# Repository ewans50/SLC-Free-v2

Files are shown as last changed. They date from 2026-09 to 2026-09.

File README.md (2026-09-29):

I'm not a creator of this product, please see https://www.14point7.com/pages/software-and-documentation for latest updates from the creator

SLC Free 2 is licensed under GNU GPL V3

Use Cypress PSOC Designer 5.4 to build/compile Firmware

Prebuilt hex files that are ready to program onto blank uCs using the PSOC Programmer Software and PSOC MiniProg hardware are contained in the "Firmware\Prebuilt_Hex" directory

PCB_Gerber_6mil_Trace_Spacing.rar in "PCB" directory are the Gerber files that you can submit to PCB fabrication places

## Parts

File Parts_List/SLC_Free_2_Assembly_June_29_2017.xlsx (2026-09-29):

Item # | Qty | PCB Ref | Value | Digikey Part No. | Package | Type | Top/Bottom
1 | 1 | C1 | 4.7uf | 399-7049-1-ND | 1210 | SMT | Top
2 | 4 | C2, C4, C5, C11 | 100nf | 1276-6557-1-ND | 805 | SMT | Top
3 | 1 | C3 | 10uf | 587-3485-1-ND | 1206 | SMT | Top
4 | 4 | C6, C7 C9, C10 | 1uf | 1276-6606-1-ND | 805 | SMT | Top
5 | 1 | C8 | 10nf | 1276-6845-1-ND | 805 | SMT | Top
6 | 1 | D1 | Diode Schottky | B190BQ-13-FDICT-ND | SMB | SMT | Top
7 | 1 | D2 | Diode TVS | F6314CT-ND | SMB | SMT | Top
8 | 1 | D3 | Diode Schottky | NRVTS245ESFT1GOSCT-ND | SOD123F | SMT | Top
9 | 1 | IC1 | NFET | 1727-5508-1-ND | TO-252 | SMT | Top
10 | 1 | IC2 | 5V Reg | NCV78M05BDTRKGOSCT-ND | TO-252-3 | SMT | Top
11 | 1 | IC3 | CY8C24423A-24PVXI | Will supply part | 28-SSOP | SMT | Top
12 | 1 | JP1 | DNP | DNP | DNP | TH | Top
13 | 1 | JP2 | DNP | DNP | DNP | TH | Top
14 | 1 | JP3 | DNP | DNP | DNP | TH | Top
15 | 1 | JP4 | DNP | DNP | DNP | TH | Top
16 | 1 | JP5 | DNP | DNP | DNP | TH | Top
17 | 1 | R1 | 10 | RMCF1206JT10R0CT-ND | 1206 | SMT | Top
18 | 1 | R14 | 4.7k | RMCF0805FT4K70CT-ND | 805 | SMT | Top
19 | 1 | R15 | 1.2k | RMCF0805FT1K20CT-ND | 805 | SMT | Top
20 | 1 | R16 | 100 | RMCF1206JT100RCT-ND | 1206 | SMT | Top
21 | 6 | R2, R6, R8, R11, R12, R13 | 1k | RMCF0805FT1K00CT-ND | 805 | SMT | Top
22 | 2 | R5,R9 | 1k 0.1% | P1.0KDACT-ND | 805 | SMT | Top
23 | 1 | R3 | 61.9 0.1% | P61.9DACT-ND | 805 | SMT | Top
24 | 1 | R10 | 10k | RMCF0805FT10K0CT-ND | 805 | SMT | Top
25 | 1 | R4 | 10k 0.1% | P10KDACT-ND | 805 | SMT | Top
26 | 1 | R7 | 120k | RMCF0805FT120KCT-ND | 805 | SMT | Top
27 | 1 | S1 | DNP | DNP | DNP | TH | Top

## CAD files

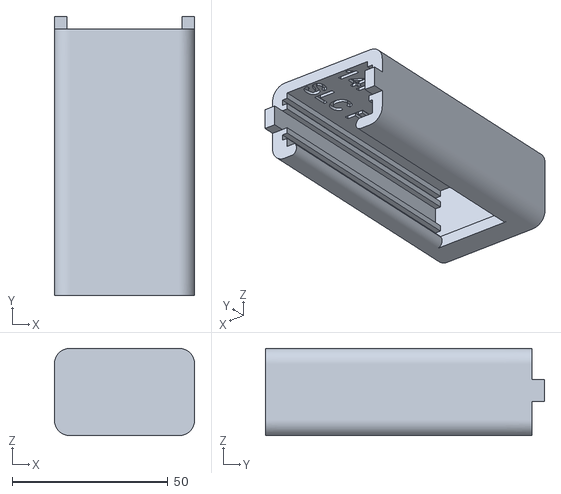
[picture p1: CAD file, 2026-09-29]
3d/STL/SF2_Case.stl
45.0 x 89.5 x 28.0

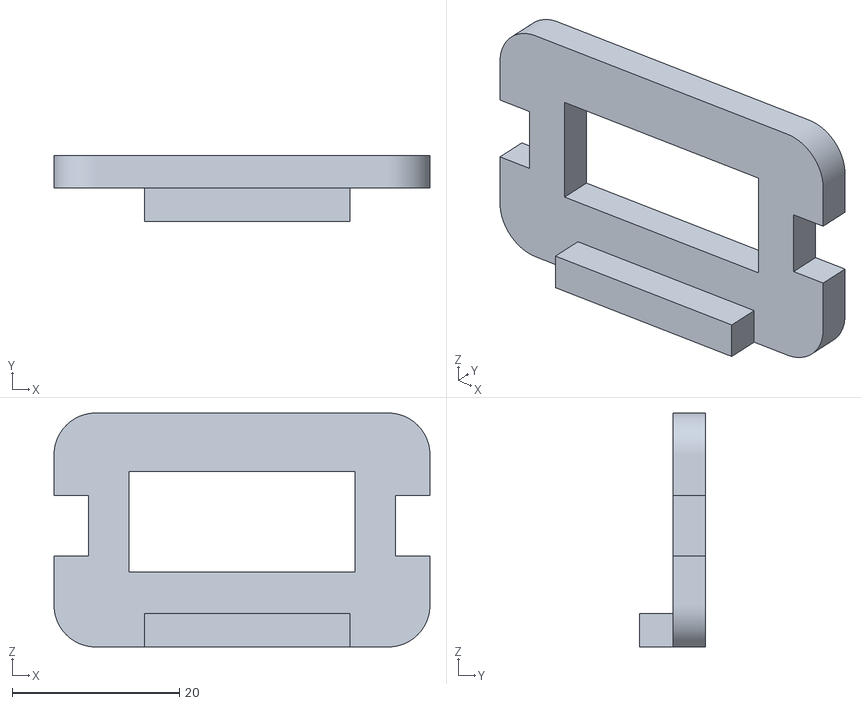
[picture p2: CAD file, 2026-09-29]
3d/STL/SF2_Cap.stl
45.0 x 7.90 x 28.0

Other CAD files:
3d/Fusion360/SF2_Cap_Jan_7_2019 v5.f3d
3d/Fusion360/SF2_Case_Jan_7_2019 v5.f3d

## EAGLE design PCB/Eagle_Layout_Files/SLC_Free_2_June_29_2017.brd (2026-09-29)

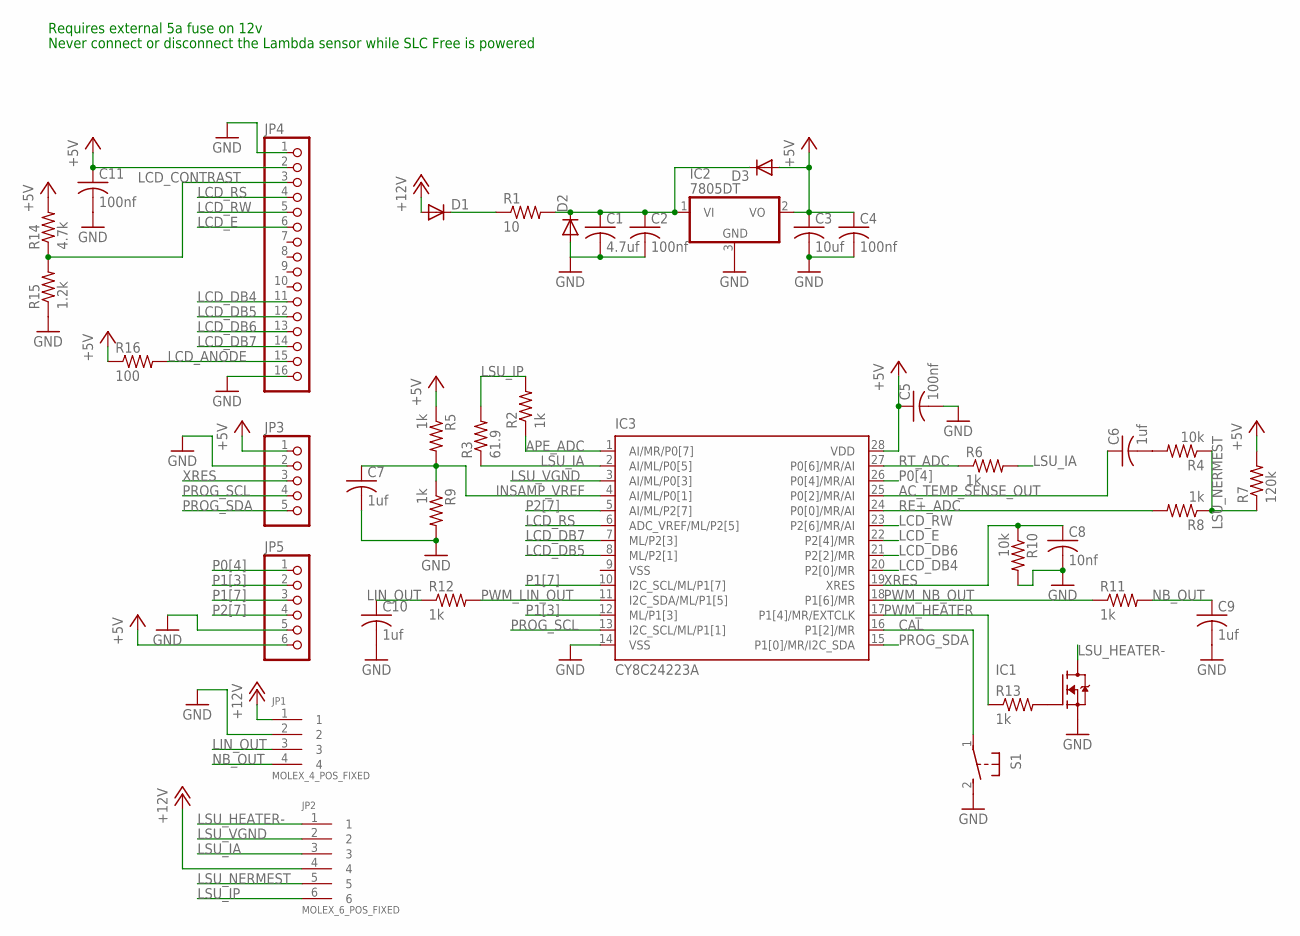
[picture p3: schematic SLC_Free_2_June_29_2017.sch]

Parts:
C1: 4.7uf; C1210
C2, C4, C5, C11: 100nf; C0805
C3: 10uf; C1206
C6, C7, C9, C10: 1uf; C0805
C8: 10nf; C0805
D1, D2: DIODE-SMB; SMB
D3: DIODE-SOD123; SOD123
IC1: FET_NMOS_T0252; T0252
IC2: 7805DT; TO252
IC3: CY8C24223A; SSOP28
JP1: MOLEX_4_POS_FIXED
JP2: MOLEX_6_POS_FIXED
JP3: PINHD-1X5; 1X05
JP4: PINHD-1X16; 1X16
JP5: PINHD-1X6; 1X06
R1: 10; R1206
R2, R5, R6, R8, R9, R11, R12, R13: 1k; R0805
R3: 61.9; R0805
R4, R10: 10k; R0805
R7: 120k; R0805
R14: 4.7k; R0805
R15: 1.2k; R0805
R16: 100; R1206
S1: 31-XX; B3F-31XX

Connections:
+5V: C3.1, C4.1, C5.1, C11.1, D3.A, IC2.2 (VO), IC3.28 (VDD), JP3.1, JP4.2, JP5.6, R5.1, R7.2, R14.2, R16.1
+12V: D1.A, JP1.1, JP2.4
AC_TEMP_SENSE_OUT: C6.1, IC3.25 (P0[2]/MR/AI)
APE_ADC: IC3.1 (AI/MR/P0[7]), R2.1
CAL: IC3.16 (P1[2]/MR), S1.1
GND: C1.2, C2.2, C3.2, C4.2, C5.2, C7.2, C8.2, C9.2, C10.2, C11.2, D2.A, IC1.2 (S), IC2.3 (GND), IC3.14 (VSS), JP1.2, JP3.2, JP4.1, JP4.16, JP5.5, R9.2, R10.2, R15.1, S1.2 (S)
INSAMP_VREF: C7.1, IC3.4 (AI/ML/P0[1]), R5.2, R9.1
LCD_ANODE: JP4.15, R16.2
LCD_CONTRAST: JP4.3, R14.1, R15.2
LCD_DB4: IC3.20 (P2[0]/MR), JP4.11
LCD_DB5: IC3.8 (ML/P2[1]), JP4.12
LCD_DB6: IC3.21 (P2[2]/MR), JP4.13
LCD_DB7: IC3.7 (ML/P2[3]), JP4.14
LCD_E: IC3.22 (P2[4]/MR), JP4.6
LCD_RS: IC3.6 (ADC_VREF/ML/P2[5]), JP4.4
LCD_RW: IC3.23 (P2[6]/MR/AI), JP4.5
LIN_OUT: C10.1, JP1.3, R12.1
LSU_HEATER-: IC1.3 (D), JP2.1
LSU_IA: IC3.2 (AI/ML/P0[5]), JP2.3, R3.1, R6.2
LSU_IP: JP2.6, R2.2, R3.2
LSU_NERMEST: JP2.5, R4.1, R7.1, R8.1
LSU_VGND: IC3.3 (AI/ML/P0[3]), JP2.2
unnamed: C6.2, R4.2
unnamed: C1.1, C2.1, D2.C, D3.C, IC2.1 (VI), R1.2
unnamed: IC1.1 (G), R13.2
unnamed: D1.C, R1.1
NB_OUT: C9.1, JP1.4, R11.2
P0[4]: IC3.26 (P0[4]/MR/AI), JP5.1
P1[3]: IC3.12 (ML/P1[3]), JP5.2
P1[7]: IC3.10 (I2C_SCL/ML/P1[7]), JP5.3
P2[7]: IC3.5 (AI/ML/P2[7]), JP5.4
PROG_SCL: IC3.13 (I2C_SCL/ML/P1[1]), JP3.4
PROG_SDA: IC3.15 (P1[0]/MR/I2C_SDA), JP3.5
PWM_HEATER: IC3.17 (P1[4]/MR/EXTCLK), R13.1
PWM_LIN_OUT: IC3.11 (I2C_SDA/ML/P1[5]), R12.2
PWM_NB_OUT: IC3.18 (P1[6]/MR), R11.1
RE+_ADC: IC3.24 (P0[0]/MR/AI), R8.2
RT_ADC: IC3.27 (P0[6]/MR/AI), R6.1
VSS: IC3.9 (VSS)
XRES: C8.1, IC3.19 (XRES), JP3.3, R10.1

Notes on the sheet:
Requires external 5a fuse on 12v
Never connect or disconnect the Lambda sensor while SLC Free is powered

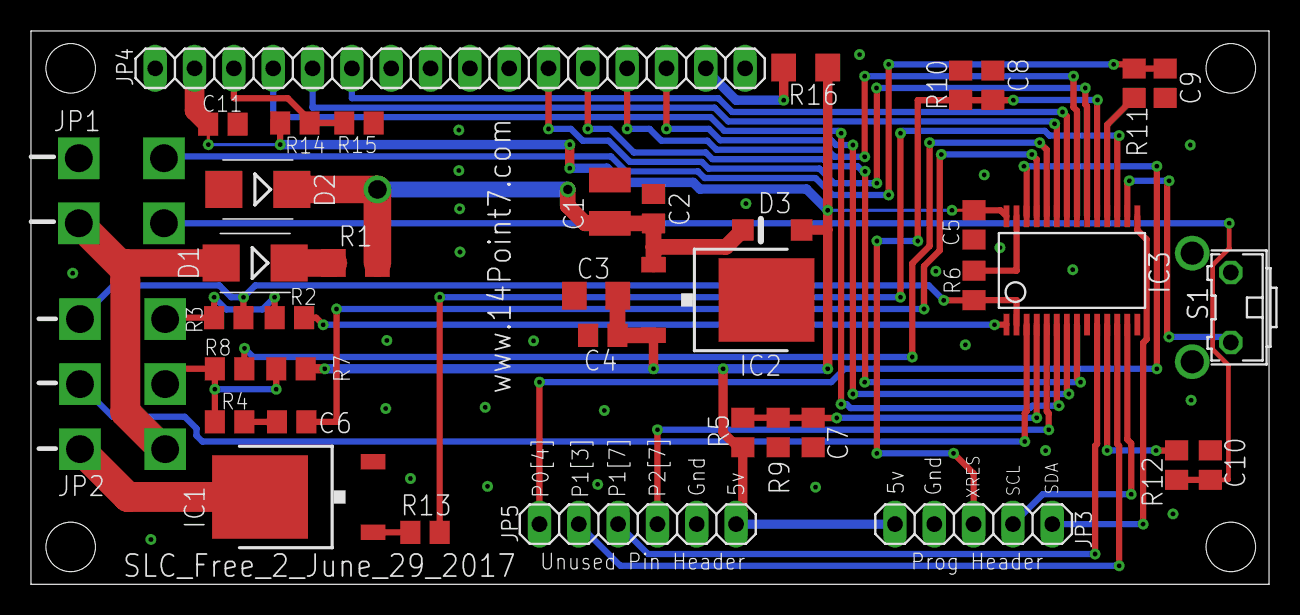
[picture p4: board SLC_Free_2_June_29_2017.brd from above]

Board: 2 copper layers, 80.0 x 35.7 mm, 39 parts (0 on the bottom side), 39 nets.

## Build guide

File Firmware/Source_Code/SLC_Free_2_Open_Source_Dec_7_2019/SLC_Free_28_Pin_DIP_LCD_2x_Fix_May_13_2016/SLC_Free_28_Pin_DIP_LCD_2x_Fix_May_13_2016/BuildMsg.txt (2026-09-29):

Starting MAKE...
creating project.mk 

lib/adcinc.asm

lib/adcincint.asm

lib/amux4_0.asm

lib/amux4_1.asm

lib/dac6_vgnd.asm

lib/dac9_ia.asm

lib/insamp.asm

lib/lcd.asm

lib/psocconfig.asm

lib/psocconfigtbl.asm

lib/pwm8_heater.asm

lib/pwm8_heaterint.asm

lib/pwm8_nb_out.asm

lib/pwm8_nb_outint.asm

lib/pwm8_vout.asm

lib/pwm8_voutint.asm

lib/sleeptimer.asm

lib/sleeptimerint.asm

./boot.asm

Linking..

symbol ADCINC_bGetData is unused

symbol SleepTimer_bGetTickCntr is unused

symbol PWM8_Heater_bReadCounter is unused

symbol ADCINC_iGetData is unused

symbol SleepTimer_iGetTickCntr is unused

symbol SleepTimer_lGetTickCntr is unused

symbol PWM8_Vout_EnableInt is unused

symbol PWM8_Vout_Stop is unused

symbol SleepTimer_TickWait is unused

symbol PWM8_Vout_bReadPulseWidth is unused

symbol PWM8_NB_Out_EnableInt is unused

symbol SleepTimer_SetTimer is unused

symbol SleepTimer_SyncWait is unused

symbol ADCINC_Stop is unused

symbol PWM8_Heater_EnableInt is unused

symbol PWM8_NB_Out_Stop is unused

symbol ADCINC_fClearFlag is unused

symbol INSAMP_Stop is unused

symbol SleepTimer_bGetTimer is unused

symbol PWM8_Heater_Stop is unused

symbol PWM8_NB_Out_bReadPulseWidth is unused

symbol SleepTimer_Stop is unused

symbol AMUX4_0_Stop is unused

symbol AMUX4_1_Stop is unused

symbol PWM8_Vout_WritePeriod is unused

symbol DAC9_Ia_Stop is unused

symbol ADCINC_WritePulseWidth is unused

symbol ADCINC_fIsDataAvailable is unused

symbol PWM8_Heater_bReadPulseWidth is unused

symbol SleepTimer_DisableInt is unused

symbol LCD_PrHexInt is unused

symbol PWM8_Vout_bReadCounter is unused

symbol DAC9_Ia_WriteBlind is unused

symbol ADCINC_cClearFlagGetData is unused

symbol AMUX4_0_Start is unused

symbol AMUX4_1_Start is unused

symbol ADCINC_StopADC is unused

symbol PWM8_NB_Out_WritePeriod is unused

symbol DAC6_VGND_Stop is unused

symbol PWM8_Heater_WritePeriod is unused

symbol PWM8_NB_Out_bReadCounter is unused

symbol INSAMP_SetGain is unused

symbol DAC6_VGND_WriteBlind is unused

427 bytes unused code deleted

3561 bytes before Code Compression, 2892 after. 6% reduction.

  ROM 91% full. 3695 out of 4096 bytes used (does not include absolute areas).

  RAM 43% full. 110 bytes used (does not include stack usage).

Built with ICCM8C STD V7.05.00

SLC_Free_28_Pin_DIP_LCD_2x_Fix_May_13_2016 - 0 error(s) 0 warning(s) 22:01:23

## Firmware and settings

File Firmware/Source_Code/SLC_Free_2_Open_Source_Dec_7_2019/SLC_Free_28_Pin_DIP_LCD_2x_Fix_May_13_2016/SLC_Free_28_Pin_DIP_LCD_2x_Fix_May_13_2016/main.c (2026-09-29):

//----------------------------------------------------------------------------
// C main line
//----------------------------------------------------------------------------

#include <m8c.h>        // part specific constants and macros
#include "PSoCAPI.h"    // PSoC API definitions for all User Modules
extern BYTE ADC_Counter; //Variable Declared in ADCININT.asm
extern BYTE Ri_Max_x1; //Variable Declared in ADCININT.asm
extern BYTE Ri_Min_x1; //Variable Declared in ADCININT.asm
extern BYTE ip_x1; //Variable Declared in ADCININT.asm
extern BYTE ADC_IF; //Variable Declared in ADCININT.asm
extern BYTE Sleep_Counter; //Variable Declared in SleepTimerINT.asm

#define Vout_Lookup_Counter_Set 25
#define LCD_Counter_Set 50

#define Lin_Out
#define NB_Out
#define LCD_Lambda_Text
//#define LCD_AFR_Text
//#define LCD_Lambda_Graph
#define LCD_Temperature_Text
//#define LCD_Temperature_Graph
//#define PID_Tune
#define Ri_Filter_Strength 4
#define ip_Filter_Strength 4

#ifdef PID_Tune
	INT Ri_Mid_Target= 286;//271; //
	INT Ia_PID_Kp = 25;
	INT Ia_PID_Ki = 4;
	INT Ia_Output_Bias = 256;
	INT Ri_Delta_Target=143; //PID Target peak to peak Voltage of Nermest Cell
	INT Heater_PID_Kp =-72;
	INT Heater_PID_Ki =-4;
	INT Heater_PID_Output_Bias =128;
#else
	#define Ri_Mid_Target 286 //271 //256+14.769 = 2.53v = 2.08v(VGND) + 0.45v, PID Target Voltage of Nermest Cell
	#define Ia_PID_Kp 25
	#define Ia_PID_Ki 4
	#define Ia_Output_Bias 256
	#define Ri_Delta_Target 143 //PID Target peak to peak Voltage of Nermest Cell
	#define Heater_PID_Kp -72
	#define Heater_PID_Ki -4
	#define Heater_PID_Output_Bias 128
#endif

#ifdef Lin_Out
	#define ip_to_Vout_Lookup_Start 135
	#define ip_to_Vout_Lookup_Size 158
	const BYTE ip_to_Vout_Lookup[ip_to_Vout_Lookup_Size] = {0,1,1,2,3,4,4,5,6,7,8,8,9,10,11,12,12,13,14,15,16,17,17,18,19,20,21,22,22,23,24,25,26,27,27,28,29,30,31,32,33,34,34,35,36,37,38,39,40,41,42,43,44,44,45,46,47,48,49,50,51,52,53,54,55,56,57,58,59,60,61,62,63,64,65,66,67,68,69,70,71,72,73,74,76,77,78,79,80,81,82,83,84,86,87,88,89,90,91,92,94,95,96,97,98,100,101,102,103,105,106,107,108,110,111,112,113,115,116,117,119,120,123,126,129,132,135,138,141,144,147,151,154,157,161,164,168,171,175,178,182,186,190,194,197,201,206,210,214,218,222,227,231,236,240,245,250,255}; 
#endif
	
#ifdef LCD_AFR_Text
	#define ip_to_Lambda_Lookup_Start 135
	#define ip_to_Lambda_Lookup_Size 158
	const BYTE ip_to_Lambda_Lookup[ip_to_Lambda_Lookup_Size]={100,100,100,101,101,101,102,102,102,103,103,103,104,104,104,105,105,105,105,106,106,106,107,107,107,108,108,108,109,109,109,110,110,110,111,111,111,112,112,112,113,113,113,114,114,115,115,115,116,116,116,117,117,117,118,118,118,119,119,120,120,120,121,121,122,122,122,123,123,123,124,124,125,125,125,126,126,127,127,127,128,128,129,129,130,130,130,131,131,132,132,133,133,133,134,134,135,135,136,136,137,137,138,138,139,139,139,140,140,141,141,142,142,143,143,144,144,145,145,146,146,147,148,149,150,152,153,154,155,156,158,159,160,162,163,164,166,167,168,170,171,173,174,176,177,179,181,182,184,185,187,189,191,192,194,196,198,200};//4.9
#endif

#ifdef LCD_Lambda_Text
	#define ip_to_Lambda_Lookup_Start 135
	#define ip_to_Lambda_Lookup_Size 158
	const BYTE ip_to_Lambda_Lookup[ip_to_Lambda_Lookup_Size]={68,68,68,69,69,69,69,69,70,70,70,70,70,71,71,71,71,72,72,72,72,72,73,73,73,73,74,74,74,74,74,75,75,75,75,76,76,76,76,76,77,77,77,77,78,78,78,78,79,79,79,79,80,80,80,80,81,81,81,81,82,82,82,82,83,83,83,83,84,84,84,85,85,85,85,86,86,86,86,87,87,87,88,88,88,88,89,89,89,90,90,90,91,91,91,91,92,92,92,93,93,93,94,94,94,95,95,95,96,96,96,97,97,97,98,98,98,99,99,99,100,100,101,102,102,103,104,105,106,106,107,108,109,110,111,112,113,114,115,116,117,118,119,120,121,122,123,124,125,126,127,128,130,131,132,133,135,136};//4.9
#endif

#ifdef LCD_Lambda_Graph
	#define ip_to_Lambda_Lookup_Start 135
	#define ip_to_Lambda_Lookup_Size 158
	const BYTE ip_to_Graph_Lookup[ip_to_Lambda_Lookup_Size]={8,8,8,9,9,9,9,9,10,10,10,10,10,11,11,11,11,12,12,12,12,12,13,13,13,13,14,14,14,14,14,15,15,15,15,16,16,16,16,16,17,17,17,17,18,18,18,18,19,19,19,19,20,20,20,20,21,21,21,21,22,22,22,22,23,23,23,23,24,24,24,25,25,25,25,26,26,26,26,27,27,27,28,28,28,28,29,29,29,30,30,30,31,31,31,31,32,32,32,33,33,33,34,34,34,35,35,35,36,36,36,37,37,37,38,38,38,39,39,39,40,40,41,42,42,43,44,45,46,46,47,48,49,50,51,52,53,54,55,56,57,58,59,60,61,62,63,64,65,66,67,68,70,71,72,73,75,76};
#endif

#ifdef LCD_Temperature_Text
	#define Ri_Delta_to_Temperature_C_Offset 740
	#define Ri_Delta_to_Temperature_C_Start 113
	#define Ri_Delta_to_Temperature_C_Size 75
	const BYTE Ri_Delta_to_Temperature_C[Ri_Delta_to_Temperature_C_Size]={80,78,77,75,74,73,71,70,68,67,65,64,63,61,60,59,58,56,55,54,52,51,50,49,48,46,45,44,43,42,41,40,39,37,36,35,34,33,32,31,30,29,28,27,26,25,24,23,22,21,20,19,18,18,17,16,15,14,13,12,11,11,10,9,8,7,6,5,5,4,3,2,1,1,0};
#endif

#ifdef LCD_Temperature_Graph
	#define Ri_Delta_to_Temperature_C_Start 113
	#define Ri_Delta_to_Temperature_C_Size 75
	const BYTE Ri_Delta_to_Graph[Ri_Delta_to_Temperature_C_Size]={80,78,77,75,74,73,71,70,68,67,65,64,63,61,60,59,58,56,55,54,52,51,50,49,48,46,45,44,43,42,41,40,39,37,36,35,34,33,32,31,30,29,28,27,26,25,24,23,22,21,20,19,18,18,17,16,15,14,13,12,11,11,10,9,8,7,6,5,5,4,3,2,1,1,0};
#endif



INT Ri_Mid_Error_Sum=0;
INT Ri_Mid;
INT Ri_Delta_Error_Sum=0;
INT Ri_Delta;
#define Ia_PID_Counter_Set 1
#define Heatup_Counter_Set 100
#define Heater_PID_Counter_Set 25
BYTE Heatup_Heater_Output=100;

INT Ri_Delta_Error;
INT Heater_Output;
INT Heater_Pout;
INT Heater_Iout;

//PID Controller, Input is Ri_Delta (The Peak to peak voltage on the Vs Port of the sensor) output is PWM8_Heater, PWM8_Heater is controlled such that Ri_Delta is maintained at 80 (80 =750C)
//Only a PI controller is used as adding the D term does not effect performance 
//Everything is inflated by a factor of 4 so that floating point is avioded
void Heater_PID(void) // Ned to run this when counter >50
{

	Ri_Delta_Error=Ri_Delta_Target-Ri_Delta;
	//Put limits on Error so PID does not go Fubar, and also so that the worst case multiplication does not overflow
	if (Ri_Delta_Error>(-127*16/Heater_PID_Kp))
	{
		Ri_Delta_Error=(-127*16/Heater_PID_Kp);
	}
	if (Ri_Delta_Error<(127*16/Heater_PID_Kp))
	{
		Ri_Delta_Error=(127*16/Heater_PID_Kp);
	}
	Heater_Pout=(Heater_PID_Kp*Ri_Delta_Error)/16;
	Ri_Delta_Error_Sum=Ri_Delta_Error_Sum+Ri_Delta_Error;
	//If the sensor is too hot, then disreguard the Integratal contribution and just use the proportional to quickly correct the sensor temperature
	/*
	if((Ri_Delta<60)&&(Ri_Delta_Error_Sum>0))
	{
		Ri_Delta_Error_Sum=0;
	}
	*/
	//Put limits on Error so PID does not go Fubar, and also so that the worst case multiplication does not overflow
	if (Ri_Delta_Error_Sum>(-127*16/Heater_PID_Ki))
	{
		Ri_Delta_Error_Sum=(-127*16/Heater_PID_Ki);
	}
	if (Ri_Delta_Error_Sum<(127*16/Heater_PID_Ki))
	{
		Ri_Delta_Error_Sum=(127*16/Heater_PID_Ki);
	}
	Heater_Iout=(Heater_PID_Ki*Ri_Delta_Error_Sum)/16;
	if (Heatup_Heater_Output<255) // if Heatup_Heater_Output is < 255 that means the unit just turned on and to give control to the heatup routine
	{
		Heater_Output=Heatup_Heater_Output;	
	}
	else
	{	
		Heater_Output=Heater_PID_Output_Bias+Heater_Pout+Heater_Iout;			
	}
	//Heater_Output=Heater_PID_Output_Bias+Heater_Pout+Heater_Iout;	
	if (Heater_Output<0)
	{
		Heater_Output=0;
	}
	if (Heater_Output>255)
	{
		Heater_Output=255;
	}


	PWM8_Heater_WritePulseWidth(Heater_Output);
	//PWM8_Heater_WritePulseWidth(200);
}

INT Ri_Mid_Error;
INT Ia_Output;
INT Ia_Pout;
INT Ia_Iout;
//PID Controller, Input is Ri_Mid (The average voltage on the Vs Port of the sensor) output is DAC9_Ia, DAC9_Ia sink/sources current to the Sensor pump cell such that Ri_Mid is is the same voltage as Vref
//Only a PI controller is used as adding the D term does not effect performance 
//Everything is inflated by a factor of 4 so that floating point is avioded
void Ia_PID(void)
{


	Ri_Mid_Error=Ri_Mid_Target-Ri_Mid;
	//Put limits on Error so PID does not go Fubar, and also so that the worst case multiplication does not overflow
	if (Ri_Mid_Error>(255*16/Ia_PID_Kp))
	{
		Ri_Mid_Error=(255*16/Ia_PID_Kp);
	}
	if (Ri_Mid_Error<(-255*16/Ia_PID_Kp))
	{
		Ri_Mid_Error=(-255*16/Ia_PID_Kp);
	}
	Ia_Pout=(Ia_PID_Kp*Ri_Mid_Error)/16;
	Ri_Mid_Error_Sum=Ri_Mid_Error_Sum+Ri_Mid_Error;
	//Put limits on Error so PID does not go Fubar, and also so that the worst case multiplication does not overflow
	if (Ri_Mid_Error_Sum>(255*16/Ia_PID_Ki))
	{
		Ri_Mid_Error_Sum=(255*16/Ia_PID_Ki);
	}
	if (Ri_Mid_Error_Sum<(-255*16/Ia_PID_Ki))
	{
		Ri_Mid_Error_Sum=(-255*16/Ia_PID_Ki);
	}
	Ia_Iout=(Ia_PID_Ki*Ri_Mid_Error_Sum)/16;
	Ia_Output=Ia_Output_Bias+Ia_Pout+Ia_Iout;
	//9 Bit Dac so only 0-511 is allowed, for some reason i put the limit at 510, I foget exactly why.
	if (Ia_Output<0)
	{
		Ia_Output=0;
	}
	if (Ia_Output>510)
	{
		Ia_Output=510;
	}
	DAC9_Ia_WriteStall (Ia_Output);
	//DAC9_Ia_WriteStall (256);
}
INT IIR_Int(INT Vin, INT Vout, BYTE A)
{
	return (Vout + (Vin - Vout)/A);
}

char btoa(BYTE Base10)
{
	char ascii;
	switch (Base10)
	{
		case 0:
			ascii='0';
			break;
		case 1:
			ascii='1';
			break;
		case 2:
			ascii='2';
			break;
		case 3:
			ascii='3';
			break;
		case 4:
			ascii='4';
			break;
		case 5:
			ascii='5';
			break;
		case 6:
			ascii='6';
			break;
		case 7:
			ascii='7';
			break;
		case 8:
			ascii='8';
			break;
		case 9:
			ascii='9';
	}
	return (ascii);
}
	BYTE Ia_PID_Counter=0;
	BYTE Vout_Lookup_Counter=0;
	BYTE Heater_PID_Counter=0;
	BYTE LCD_Counter=0;
	BYTE Heatup_Counter=0;
	INT Ri_Min,Ri_Max;
	INT ip,ip_Justified;
	BYTE Lambda_x100;
	INT LSU_Temperature_C;
	char Str1[] = "Lambda=x.xx";
	char Str2[] = "Temperature=xxxC"; 
	char Str3[] = "AFR=xx.x";
void main(void)
{
	unsigned long temp_ulong;
	INT temp_int,temp_int2;
	BYTE temp_byte;
	AMUX4_0_InputSelect(AMUX4_0_PORT0_1);        
   	AMUX4_1_InputSelect(AMUX4_1_PORT0_0);
   	INSAMP_Start(INSAMP_LOWPOWER); 
    ADCINC_Start(ADCINC_HIGHPOWER);      
   	DAC9_Ia_Start(DAC9_Ia_HIGHPOWER);
	DAC6_VGND_Start(DAC6_VGND_MEDPOWER);
	DAC6_VGND_WriteStall (31);
    PWM8_Vout_DisableInt();  
    PWM8_Vout_Start();     
    PWM8_Heater_DisableInt();  
    PWM8_Heater_Start();
	PWM8_NB_Out_DisableInt();  
    PWM8_NB_Out_Start(); 
	ADCINC_GetSamples(0);
	SleepTimer_Start();  
   	SleepTimer_SetInterval(SleepTimer_512_HZ);  
   	SleepTimer_EnableInt();   
	M8C_EnableGInt ;  
	LCD_Start();                  // Initialize LCD
	//LCD_InitBG(LCD_SOLID_BG);

	for(;;)
    {
		temp_ulong++;
		if ((ADC_IF&1)==1)
		{
			ADC_IF=ADC_IF&254;
			Ri_Min=IIR_Int(Ri_Min_x1*2,Ri_Min,Ri_Filter_Strength);
			Ri_Delta=Ri_Max-Ri_Min;
			Ri_Mid=(Ri_Max+Ri_Min)/2;
		}
		if ((ADC_IF&2)==2)
		{
			ADC_IF=ADC_IF&253;
			Ri_Max=IIR_Int(Ri_Max_x1*2,Ri_Max,Ri_Filter_Strength);
			Ri_Delta=Ri_Max-Ri_Min;
			Ri_Mid=(Ri_Max+Ri_Min)/2;
		}
		if ((ADC_IF&4)==4)
		{
			ADC_IF=ADC_IF&251;
			ip=IIR_Int(ip_x1*2,ip,ip_Filter_Strength);
		}
		Ia_PID_Counter+=Sleep_Counter;
		Heater_PID_Counter+=Sleep_Counter;
		Heatup_Counter+=Sleep_Counter;
		Vout_Lookup_Counter+=Sleep_Counter;
		LCD_Counter+=Sleep_Counter;
		Sleep_Counter=0;
		if (Ia_PID_Counter>Ia_PID_Counter_Set)
		{
			Ia_PID_Counter=0;
			Ia_PID();
		}
		if (Heater_PID_Counter>Heater_PID_Counter_Set)
		{
			Heater_PID_Counter=0;
			Heater_PID();
		}
		if (Vout_Lookup_Counter>Vout_Lookup_Counter_Set)
		{
			Vout_Lookup_Counter=0;
			temp_int=ip-ip_to_Vout_Lookup_Start;
			if (temp_int<0)
			{
				temp_int=0;
			}
			if (temp_int>(ip_to_Vout_Lookup_Size-1))
			{
				temp_int=(ip_to_Vout_Lookup_Size-1);
			}
			PWM8_Vout_WritePulseWidth(ip_to_Vout_Lookup[temp_int]);
			
			#ifdef NB_Out
				temp_byte=23;//0.45v
				if (ip<251) // 251 =0.9797787392968
				{
					temp_byte=46; //0.9v
					
				}
				if (ip>259) //259 = 1.02295956968912
				{
					temp_byte=0; //0v
				}
				PWM8_NB_Out_WritePulseWidth(temp_byte);
			#endif
			
		}
		if (LCD_Counter>LCD_Counter_Set)
		{
			LCD_Counter=0;
			
			#ifdef LCD_AFR_Text
				temp_int=ip-ip_to_Lambda_Lookup_Start;
				if (temp_int<0)
				{
					temp_int=0;
				}
				if (temp_int>(ip_to_Lambda_Lookup_Size-1))
				{
					temp_int=(ip_to_Lambda_Lookup_Size-1);
				}
				Lambda_x100=ip_to_Lambda_Lookup[temp_int];
				temp_int=Lambda_x100;
				LCD_Position(0,0);
				temp_int2=temp_int/100;
				Str3[4]=btoa(temp_int2);
				temp_int=temp_int-100*temp_int2;
				temp_int2=temp_int/10;
				Str3[5]=btoa(temp_int2);
				temp_int=temp_int-10*temp_int2;
				Str3[7]=btoa(temp_int);
				LCD_PrString(Str3);
			#endif
			
			#ifdef LCD_Lambda_Text
				temp_int=ip-ip_to_Lambda_Lookup_Start;
				if (temp_int<0)
				{
					temp_int=0;
				}
				if (temp_int>(ip_to_Lambda_Lookup_Size-1))
				{
					temp_int=(ip_to_Lambda_Lookup_Size-1);
				}
				Lambda_x100=ip_to_Lambda_Lookup[temp_int];
				temp_int=Lambda_x100;
				LCD_Position(0,0);
				temp_int2=temp_int/100;
				Str1[7]=btoa(temp_int2);
				temp_int=temp_int-100*temp_int2;
				temp_int2=temp_int/10;
				Str1[9]=btoa(temp_int2);
				temp_int=temp_int-10*temp_int2;
				Str1[10]=btoa(temp_int);
				LCD_PrString(Str1);
			#endif
			
			#ifdef LCD_Lambda_Graph
				temp_int=ip-ip_to_Lambda_Lookup_Start;
				if (temp_int<0)
				{
					temp_int=0;
				}
				if (temp_int>(ip_to_Lambda_Lookup_Size-1))
				{
					temp_int=(ip_to_Lambda_Lookup_Size-1);
				}
				Lambda_x100=ip_to_Graph_Lookup[temp_int];
				LCD_DrawBG(0,0,16,Lambda_x100);
			#endif
			
			#ifdef LCD_Temperature_Text
				temp_int=Ri_Delta-Ri_Delta_to_Temperature_C_Start;
				if (temp_int<0)
				{
					temp_int=0;
				}
				if (temp_int>(Ri_Delta_to_Temperature_C_Size-1))
				{
					temp_int=(Ri_Delta_to_Temperature_C_Size-1);
				}
				LSU_Temperature_C=Ri_Delta_to_Temperature_C[temp_int]+Ri_Delta_to_Temperature_C_Offset;
				temp_int=LSU_Temperature_C;
				LCD_Position(1,0);           
				temp_int2=temp_int/100;
				Str2[12]=btoa(temp_int2);
				temp_int=temp_int-100*temp_int2;
				temp_int2=temp_int/10;
				Str2[13]=btoa(temp_int2);
				temp_int=temp_int-10*temp_int2;
				Str2[14]=btoa(temp_int);
				LCD_PrString(Str2);
			#endif
			
			#ifdef LCD_Temperature_Graph
				temp_int=Ri_Delta-Ri_Delta_to_Temperature_C_Start;
				if (temp_int<0)
				{
					temp_int=0;
				}
				if (temp_int>(Ri_Delta_to_Temperature_C_Size-1))
				{
					temp_int=(Ri_Delta_to_Temperature_C_Size-1);
				}
				LSU_Temperature_C=Ri_Delta_to_Graph[temp_int];
				LCD_DrawBG(1,0,16,LSU_Temperature_C);
			#endif
		}
		if (Heatup_Heater_Output<255)
		{   
			if (Heatup_Counter>Heatup_Counter_Set)
			{
				Heatup_Counter=0;
				Heatup_Heater_Output++;
			}
			if ((Ri_Min>50) && (Ri_Max<475) && (Ri_Delta<Ri_Delta_Target))
			{
				Heatup_Heater_Output=255;
				Ri_Delta_Error_Sum=0;
			}
		}
	}
}
